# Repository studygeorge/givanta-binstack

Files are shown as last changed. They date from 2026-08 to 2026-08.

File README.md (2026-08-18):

# BINSTACK — настольный органайзер электронщика

**GIVANTA MASTERS** · мебель для тех, кто делает вещи руками

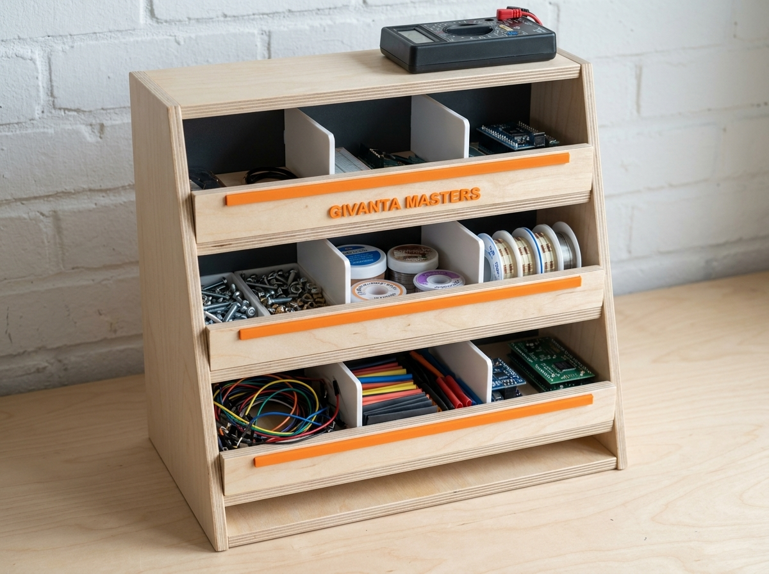
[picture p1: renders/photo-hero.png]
BINSTACK


Трёхъярусный настольный минишкафчик с наклонными открытыми лотками: винтики,
флюсы, припой, провода, термоусадка — всё видно и всё на расстоянии пальцев.
Спроектирован в Fusion 360. **Две версии в одном репозитории**: из фанеры
12 мм и полностью печатная на 3D-принтере (детали до 250×250×250 мм).

---

## Кому и зачем

Рабочее место электронщика: паяешь, собираешь макетки, прошиваешь
микроконтроллеры. Каждый ярус наклонён на 12° — содержимое сползает к
переднему бортику, откуда его удобно брать. Перегородки делят ярус на три
отсека: крепёж / химия и припой / провода. Верх — полочка под мультиметр.

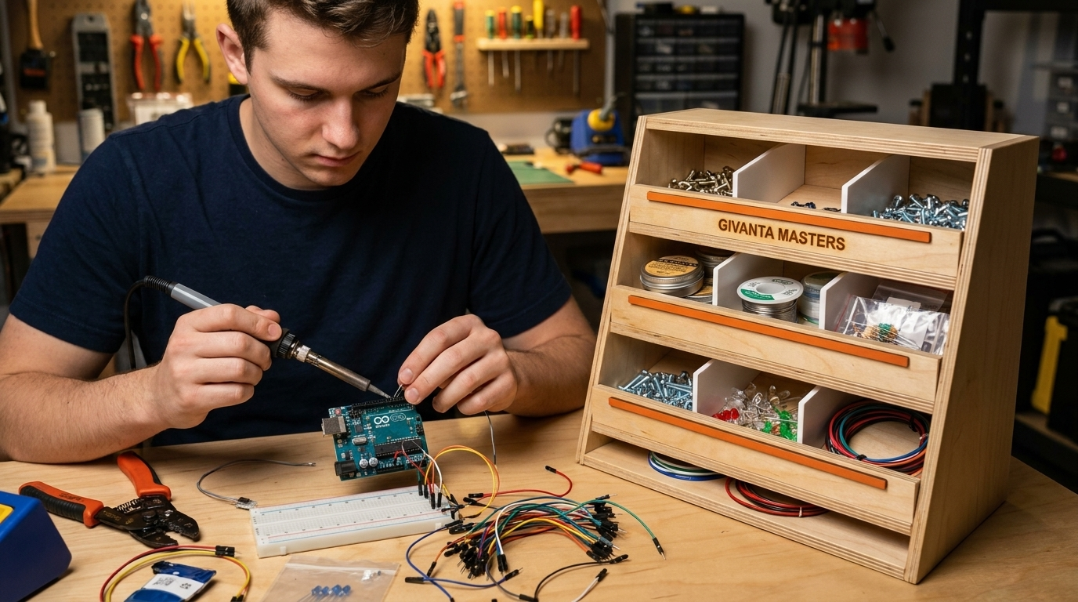
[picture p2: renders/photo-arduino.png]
За работой


## Версия из фанеры

Габарит 420 × 240 × 390 мм, берёзовая фанера 12 мм + ХДФ 6 мм.

| | |
|---|---|
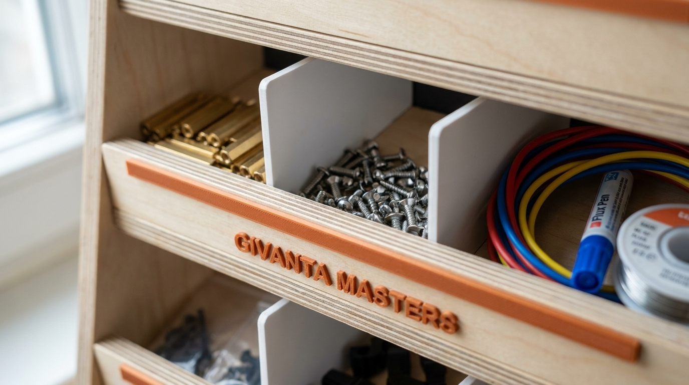
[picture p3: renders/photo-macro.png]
Фото
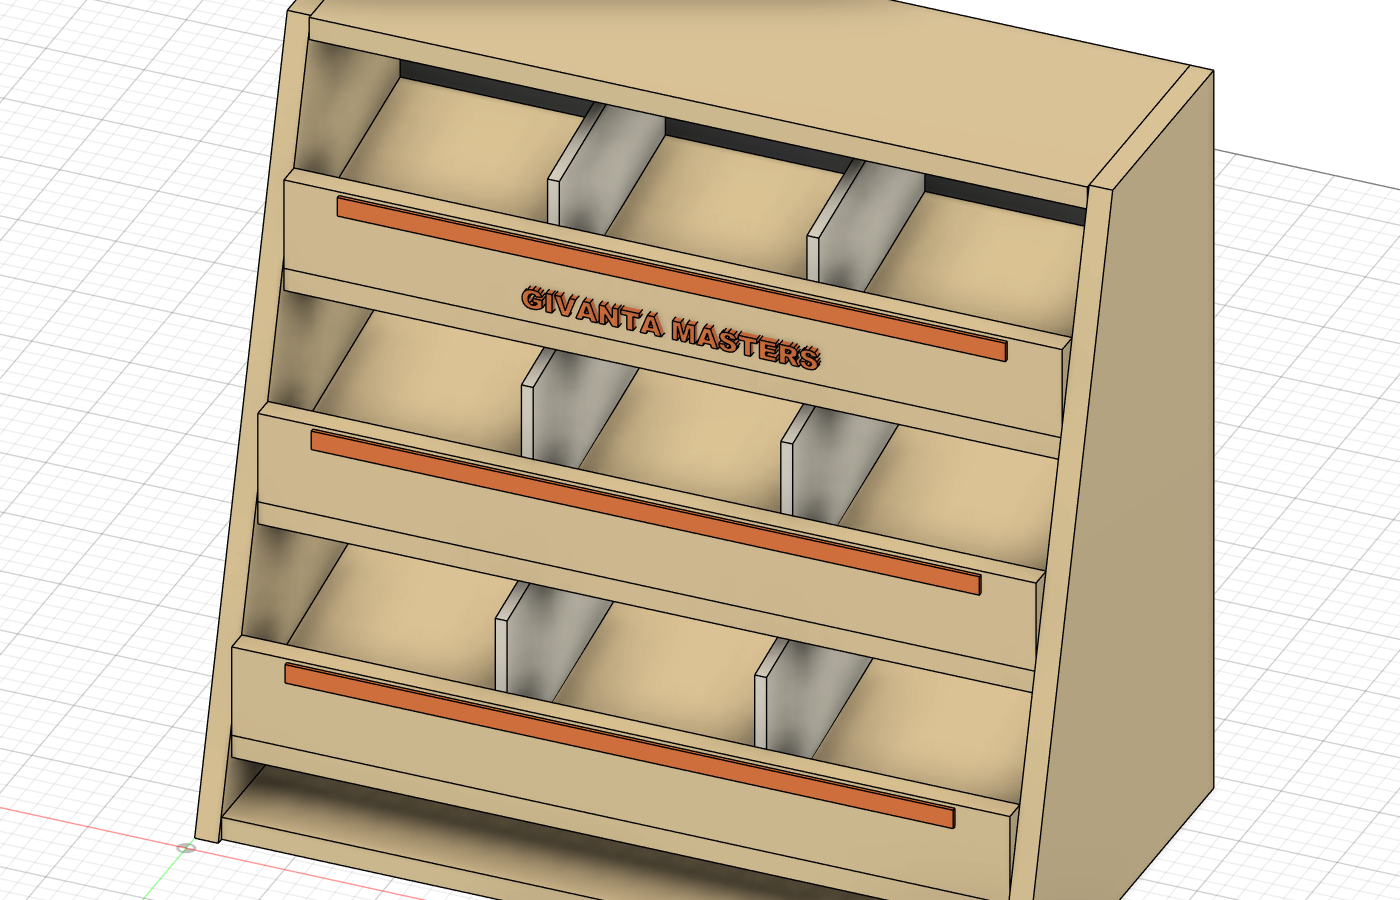
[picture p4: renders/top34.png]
Модель
|  |  |

- Косые боковины, три наклонных лотка с бортиками 48 мм
- 9 отсеков (перегородки переставные), полочка сверху
- Оранжевые маркировочные планки на бортиках — печать PETG
- Сборка на шканты 6×30 и клей ПВА, ~1 час
- Карта раскроя: [docs/cutlist.csv](docs/cutlist.csv)

**Чертёж** (SVG также в [docs/drawings](docs/drawings)):

Чертёж BINSTACK

## Печатная версия BINSTACK P

Для тех, у кого есть 3D-принтер и нет циркулярки. Все детали помещаются на
стол 250×250×250, печать **без поддержек**, комплект ~445 г PETG
(боковины облегчены фермой, см. ниже).

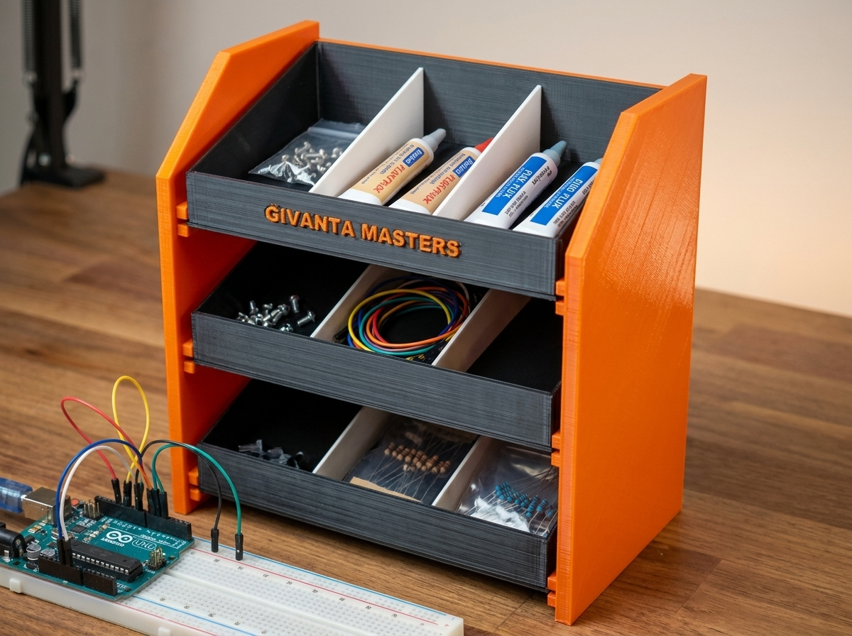
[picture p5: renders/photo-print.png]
Печатная версия


| | |
|---|---|
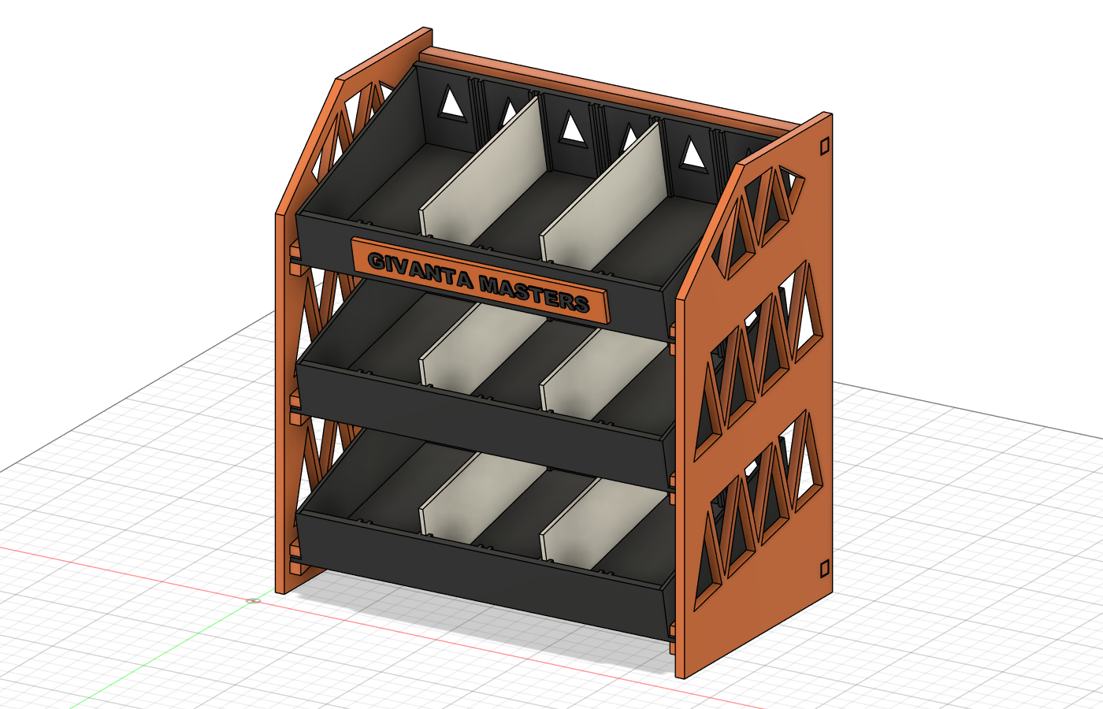
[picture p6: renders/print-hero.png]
Сборка
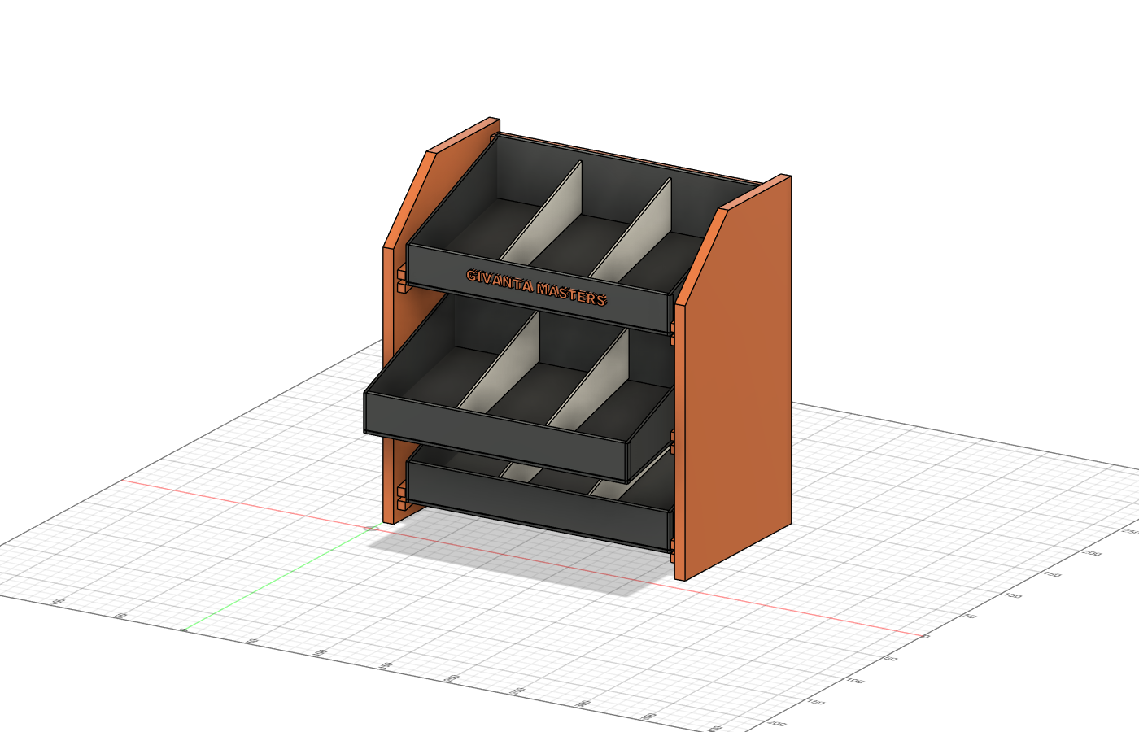
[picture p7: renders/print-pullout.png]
Выдвижение лотка
|  |  |

Конструкция: две боковины-лесенки с интегрированными полозьями под 12°,
лотки задвигаются как ящики, две штанги стягивают каркас.

**На чём лоток ездит:**
- **Дно лотка шире корпуса на 6 мм с каждой стороны.** Эти выступающие
  фланцы и есть салазки: они лежат в пазу между верхним и нижним полозом
  боковины (перекрытие 5,5 мм). Паз 3,2 мм, дно 2,4 мм — зазор 0,4 на
  сторону по нашей базе печати. Больше в конструкции ничего не требуется:
  ни направляющих, ни метизов.
- Наклон 12° работает на удержание: сам лоток внутрь не сползает, а ход
  назад ограничен задними штангами.

**На чём держатся перегородки:**
На передней и задней стенке лотка напечатаны пары рёбер, образующие
вертикальный паз 3,2 мм. Перегородка (2,4 мм) вставляется в него сверху,
стоит на дне и торцами упирается в стенки: вбок не ездит, не падает,
вынимается вверх пальцами. Пазов **5 на лоток** (шаг 33 мм), так что
перегородки переставляются под размер того, что в них лежит: от одного
широкого отсека до шести узких (перегородки докупать не нужно, просто
напечатать ещё — деталь одна и та же).
- **Детент-упор** — главное, что держит лоток от произвольного выезда. На
  переднем конце каждого нижнего полоза напечатан бугорок 1,0 мм с пологим
  въездом и крутым сходом (люфт паза 0,8 плюс натяг 0,2, поэтому дно
  поджимается и щёлкает, а не просто переезжает ступеньку). Дно лотка перещёлкивается через него с ощутимым
  усилием: закрытый лоток не выедет от тряски стола или толчка, а на выезде
  бугорок ловит лоток, не давая ему выпасть из полозьев целиком.
  Чтобы снять лоток полностью — приподнять перед и протянуть через упор.
- **Движение**: тянешь за передний бортик, щелчок — лоток выехал; толкаешь
  назад до упора в штангу, щелчок — закрыт.

Полозья и детент
- **Каркас** собирается на сквозные шипы: у каждой штанги на торцах шипы
  6×6×8, они проходят через окна 7×7 в боковинах и выходят заподлицо
  снаружи — столярный узел, никакого клея. При желании фиксируется каплей
  цианакрилата или самореза в торец шипа.

**Раскладка на столе принтера 250×250** — 5 столов на комплект:
боковина (стол целиком, полозьями вверх), боковина зеркальная, и три стола
«лоток + 2 перегородки + штанга» (штанги на первых двух из них):

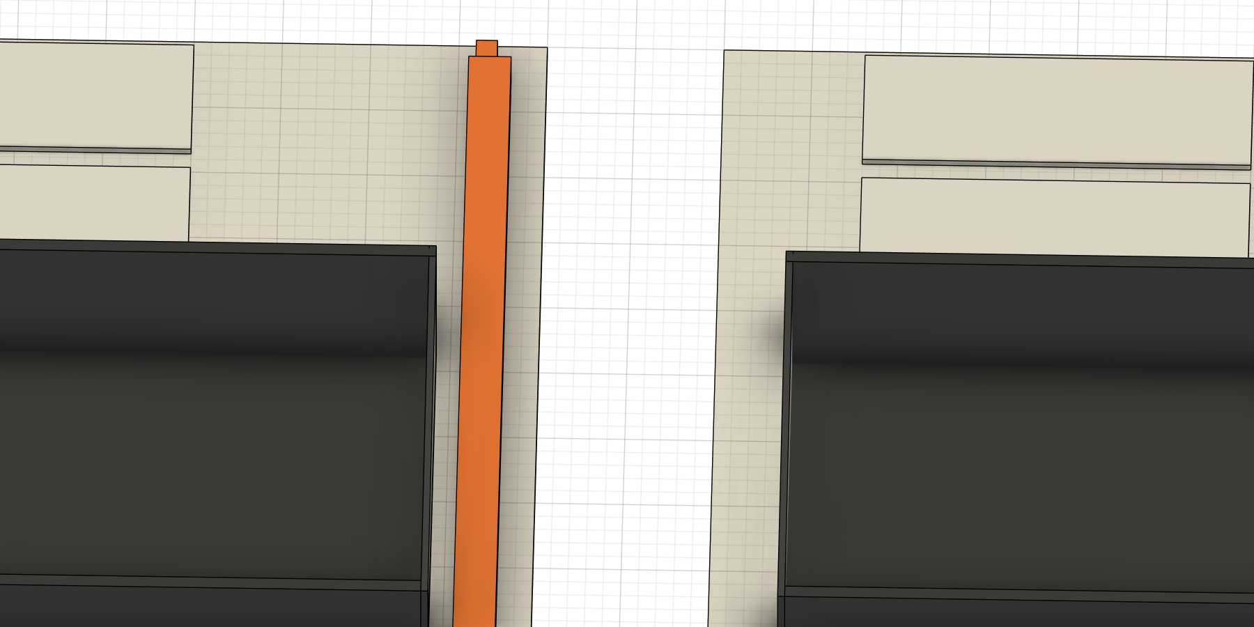
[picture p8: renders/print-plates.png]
Раскладка печати


| Файл | Деталь | Кол-во | Ориентация печати |
|---|---|---|---|
| [print/bp-side-panel.stl](print/bp-side-panel.stl) | боковина-ферма с полозьями и детентами, 240×150×11 | 2 (одна зеркально) | плашмя, полозьями вверх |
| [print/bp-bin.stl](print/bp-bin.stl) | лоток 213×117×45 (дно с фланцами-салазками) | 3 | дном вниз |
| [print/bp-stretcher.stl](print/bp-stretcher.stl) | штанга с шипами, 222 мм | 2 | лёжа |
| [print/bp-divider.stl](print/bp-divider.stl) | перегородка 109×40×2,4 | 6 (или больше) | плашмя |
| [print/bp-logo-strip.stl](print/bp-logo-strip.stl) | планка с логотипом, 138×17×3 | 1 | лицом вверх |

**Планка логотипа — двухцветная.** Буквы выступают ровно на 0,8 мм над
планкой и лежат выше всей её толщины, поэтому цвет меняется одной паузой:
печатать лицом вверх и поставить смену филамента на высоте **3,0 мм**
(в Creality Print: правый клик по слою → Add color change). Оранжевая
планка, графитовые буквы. Если менять филамент не хочется, деталь
печатается одним цветом и буквы читаются рельефом.

Режим: PETG, сопло 0,4, слой 0,2, заполнение 15 %, стенки 3 периметра.
Посадки: паз полоза 3,2 мм под дно 2,4 (зазор 0,4 на сторону), шипы штанг
6×6 в карманы 7×7. Зеркальную боковину слайсер делает функцией Mirror.

### Облегчение по сопромату

Боковины сделаны не сплошными пластинами, а **фермами** — как рама
велосипеда, где металл стоит только там, где работает.

Ферма боковины

Расчёт: при 4,5 кг груза (три полных лотка) на боковину приходится 22 Н.
Сдвиг в стенке 0,018 МПа против предела PETG ~50 МПа, изгиб полоза 0,06 МПа.
**Запас по прочности ~2700 крат** — то есть прочность вообще не ограничивает
конструкцию, ограничивает только жёсткость. Поэтому материал убран из всех
зон, где он не работает:

| Что оставлено | Зачем |
|---|---|
| силовой контур 7 мм по периметру | момент инерции сечения: чем дальше материал от нейтральной оси, тем выше жёсткость |
| полосы 4 мм вдоль полозьев | локальная нагрузка от фланцев лотков |
| раскосы 4 мм треугольной решёткой | треугольник не деформируется без изменения длины сторон, поэтому ферма держит форму при минимуме материала |
| перемычки у окон под шипы | концентрация напряжений в узле каркаса |
| толщина стенки 5 мм вместо 8 | стенка сдвинута к полозьям, посадки лотков не изменились |

Проёмы наклонены вдоль полозьев на 12°, углы у них тупые (нет острых
концентраторов, от которых по слоям идёт трещина). Отверстия сквозные по
толщине, поэтому при печати плашмя **нависаний не возникает вообще**.

Ферма покрывает и клин над верхним полозом, а у лотков треугольными
проёмами облегчены задние стенки: низ борта 17 мм оставлен сплошным, чтобы
мелочь не просыпалась, а сами проёмы стоят **строго между пазами
перегородок** и их рёбер не касаются.

Каждый проём проходит три проверки, иначе не режется вовсе: площадь ≥ 200 мм²,
радиус вписанной окружности ≥ 4,5 мм и отношение этого радиуса к длинной
стороне ≥ 0,13. Последнее отсекает вырожденные щели и обрезки у краёв —
поэтому в узком клине под нижним полозом материал намеренно оставлен
сплошным: там аккуратный проём не помещается.

Результат: боковина **272 → 131 см³ (−52 %)**, лоток 132 → 128 см³,
комплект целиком 771 см³. По факту слайсинга это **503 г PETG и 31 ч 39 мин** печати (см. замеры ниже).

### Профиль печати: минимум пластика и времени

Числа под Creality K2, сопло 0,4, PETG 230–240 °C / стол 70–80 °C.

**Когда слайсер перестаёт лить сплошняк.** Ширина линии для сопла 0,4 равна
0,42 мм, поэтому при 2 периметрах деталь толщиной до **1,7 мм печатается
насквозь сплошной**, от 1,7 до 2,1 мм слайсер добивает остаток gap fill —
это тоже сплошной пластик, и только **от 2,1 мм** внутри появляется полость
с заполнением. При 3 периметрах те же пороги сдвигаются до 2,5 и 2,9 мм.

| Толщина элемента | 2 периметра | 3 периметра |
|---|---|---|
| до 1,7 мм | сплошняк | сплошняк |
| 1,7–2,1 мм | сплошняк (gap fill) | сплошняк |
| 2,1–2,5 мм | **полость с заполнением** | сплошняк |
| 2,5–2,9 мм | полость | сплошняк (gap fill) |
| от 2,9 мм | полость | **полость** |

**Что получится в стенке 5 мм.** Боковина печатается плашмя, поэтому 5 мм
это высота по Z (20 слоёв по 0,25), а ширина раскоса 4 мм лежит на столе.
В сечении раскоса 4 × 5 мм:

| | Размер | Доля сечения |
|---|---|---|
| сплошные верхние слои | 0,75 мм (3 слоя) | |
| сплошные нижние слои | 0,75 мм (3 слоя) | |
| сплошные периметры по бокам | 0,84 + 0,84 мм | |
| **всего сплошного** | **11,9 мм²** | **59 %** |
| **полость** | 2,32 × 3,50 мм = **8,1 мм²** | **41 %** |
| в полость идёт Gyroid 10 % | 0,8 мм² | |
| **итого пластика** | **12,7 мм²** из 20 | **63 %** |

Сечение раскоса

**По слоям (Z).** Стенка 5 мм при слое 0,25 это ровно 20 слоёв:

| Слои | Z, мм | Что печатает принтер |
|---|---|---|
| 1–3 | 0 … 0,75 | сплошная нижняя корка, 100 % |
| 4–17 | 0,75 … 4,25 | **Gyroid 10 %**, 14 слоёв = 3,50 мм |
| 18–20 | 4,25 … 5,0 | сплошная верхняя корка, 100 % |

Гироид идёт только в полости шириной 2,32 мм: по краям раскоса на всех
20 слоях всё равно печатаются два периметра 0,84 мм — они сплошные всегда.
При 2 корках вместо 3 раскладка становится 0,50 / 4,00 / 0,50 мм.

Если нужно ещё легче — поставить 2/2 слоя вместо 3/3, будет 58 %.
Три периметра ставить нельзя: полость схлопнется до 1,5 мм, а пластика
станет 77 %, то есть почти сплошняк.

Поэтому раскосы фермы сделаны **4 мм**: при 2 периметрах внутри остаётся
2,3 мм полости, то есть раскос печатается как две стенки с воздухом внутри,
а не бруском пластика. Перегородка (2,4 мм) наоборот идёт сплошняком из
периметров — заполнение ей просто не нужно.

| Деталь | Слой | Стенки | Заполнение | Дно/верх |
|---|---|---|---|---|
| боковина-ферма | 0,25 | 2 | **Lightning 5 %** | 2 / 2 |
| лоток | 0,25 | 2 | Lightning 5 % | 4 / 3 |
| перегородка 2,4 мм | 0,25 | 2 | не нужно: деталь целиком из периметров | 2 / 2 |
| штанга | 0,25 | 3 | Gyroid 15 % (несёт каркас) | 3 / 3 |
| планка логотипа | 0,2 | 2 | 10 % | 3 / 4 |

**Какой узор выгоднее — замерено, а не прикинуто.** Боковина-ферма
нарезана в Creality Print CLI под PETG, слой 0,25, 2 периметра, 3/3 корки,
заполнение 10 %:

| Узор | Время | Пластик |
|---|---|---|
| **Lightning** | **7 ч 10 мин** | **65,1 г** |
| Grid | 7 ч 54 мин | 75,2 г |
| Rectilinear | 7 ч 54 мин | 75,2 г |
| Gyroid | 7 ч 59 мин | 76,0 г |
| Honeycomb | 8 ч 48 мин | 79,0 г |

Lightning выигрывает и по времени, и по расходу: минус 11 г и 49 минут
против Gyroid на каждой боковине. Grid и Rectilinear в этой детали дают
идентичный результат, соты — худший вариант по обоим параметрам.

Дожимаем корками и процентом (тот же Lightning):

| Настройка | Время | Пластик |
|---|---|---|
| 10 %, корки 3/3 | 7 ч 10 мин | 65,1 г |
| 10 %, корки 2/2 | 6 ч 58 мин | 63,5 г |
| 5 %, корки 3/3 | 6 ч 30 мин | 62,5 г |
| **5 %, корки 2/2** | **6 ч 17 мин** | **60,8 г** |

Итог: **Lightning 5 %, корки 2/2** — 60,8 г и 6 ч 17 мин против 76 г и
8 часов у Gyroid 10 % с корками 3/3. Экономия 15 г и 1 ч 40 мин на боковину,
то есть **30 г и больше трёх часов на пару**.

Почему Lightning здесь безопасен, хотя обычно он «несущим» не считается:
в раскосе шириной 4 мм полость всего 2,3 мм, и жёсткость там дают два
периметра, а не заполнение. Для штанг каркаса, где сечение 12 × 10 мм,
заполнение работает по-настоящему — там ставим Gyroid 15 %.

**Весь комплект, замерено по каждой детали** (профили из таблицы выше):

| Деталь | Шт | Время / шт | Грамм / шт | Время всего | Грамм всего |
|---|---|---|---|---|---|
| Боковина-ферма | 2 | 6 ч 17 мин | 60,8 | 12 ч 34 мин | 121,7 |
| **Лоток** | 3 | 4 ч 20 мин | **98,0** | 12 ч 59 мин | **294,1** |
| Перегородка | 6 | 36 мин | 8,7 | 3 ч 38 мин | 52,0 |
| Штанга | 2 | 58 мин | 14,7 | 1 ч 56 мин | 29,3 |
| Планка логотипа | 1 | 30 мин | 6,1 | 30 мин | 6,1 |
| **Итого** | **14** | | | **31 ч 39 мин** | **503 г** |

Важный вывод: после облегчения боковин главным потребителем стали **лотки —
58 % пластика и 41 % времени всего комплекта**. Причина в дне: 213 × 117 мм
при толщине 2,4 мм это 10 слоёв, из которых при корках 4/3 семь идут
сплошной заливкой, то есть дно печатается почти монолитом независимо от
процента заполнения. Настройками это не лечится, только геометрией
(утоньшить середину дна и добавить рёбра жёсткости) — скажи, если делать.

Общее: **без поддержек** (`enable_support: 0`), кайма 5 мм outer only,
elephant foot 0,15, скорости стенок 150–200 мм/с (PETG выше мутит
поверхность), обдув 30–50 %.

Проверять в слайсере просто: в Preview включить показ слоёв и посмотреть
срез через раскос — должны быть видны два контура и воздух между ними.
Если сплошная заливка, значит ширина линии в профиле больше 0,42 или
периметров стоит 3.

Посадки печатать слоем 0,25 и не выше: по нашей базе 0,28 экономит около
7 % времени, но портит пазы.

### Тест-кит перед печатью комплекта

Прежде чем печатать боковины целиком, проверь посадку и поведение на наклоне
маленьким китом: 33 минуты и 7,5 г PETG на все четыре купона.

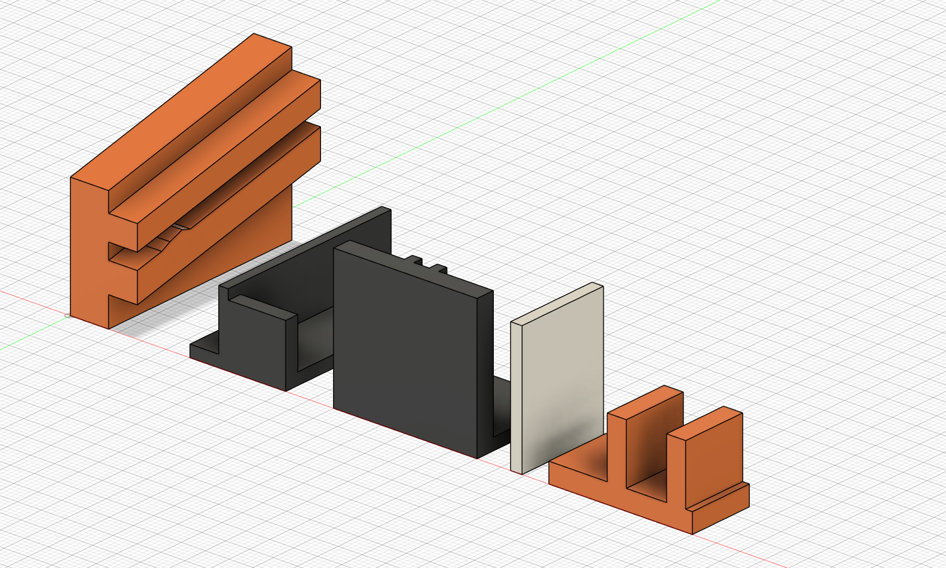
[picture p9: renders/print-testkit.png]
Тест-кит


Четыре маленьких купона с **точно теми же припусками**, что в изделии.

| Файл | Что это | Размер |
|---|---|---|
| [print/tk3-rail-coupon.stl](print/tk3-rail-coupon.stl) | кусок боковины: наклонный полоз 12° + детент | 35×26×10, 5 см³ |
| [print/tk3-slider-flange.stl](print/tk3-slider-flange.stl) | кусок дна лотка с фланцем-салазкой | 14×30×10, 2 см³ |
| [print/tk3-divider-slot.stl](print/tk3-divider-slot.stl) | кусок стенки лотка с пазом под перегородку | 24×18×12, 2 см³ |
| [print/tk3-divider.stl](print/tk3-divider.stl) | огрызок перегородки | 18×16×2,4, 1 см³ |

Все четыре купона уже лежат в печатной ориентации: высота набора 12 мм,
48 слоёв, **33 минуты и 7,5 г PETG** на всё (слой 0,25, стенки 2,
заполнение 10 %, без поддержек).

Что проверяем:

1. **Паз перегородки.** Вставь огрызок перегородки в паз купона: должен
   входить пальцем без молотка, но не болтаться. Расчётный люфт 0,8 мм
   (паз 3,2 − перегородка 2,4).
2. **Ход по полозьям.** Поставь купон полоза на торец (полозья тогда идут
   под рабочим наклоном 12°), вставь слайдер фланцем в паз и двигай: ход
   должен быть свободным, без закусывания на стыках слоёв. Перекрытие
   фланца с полозом 5,5 мм.
3. **Детент.** На выезде слайдер должен **щёлкнуть** через бугорок: он
   выше люфта на 0,2 мм, то есть дно поджимается. Задвинутый слайдер не
   должен сам стронуться, если стукнуть по столу.

Если посадка окажется тугой или болтающейся — скажи, какая именно, и все
пазы пересчитываются одним параметром в скрипте.

## CAD

Печатная версия собрана как настоящая сборка: каждая деталь это отдельный
парт с одним телом, сборка состоит из экземпляров этих партов.

| Файл | Что внутри |
|---|---|
| [cad/binstack-print-assembly.f3d](cad/binstack-print-assembly.f3d) | сборка BINSTACK P для Fusion 360: 6 партов, 14 экземпляров |
| [cad/binstack-print-assembly.step](cad/binstack-print-assembly.step) | та же сборка в нейтральном формате |
| [cad/parts/](cad/parts) | каждый парт отдельным файлом: боковины, лоток, перегородка, штанга, планка |
| [cad/binstack-full.step](cad/binstack-full.step) | фанерная версия |

Состав сборки: боковина левая ×1, боковина правая ×1, лоток ×3,
перегородка ×6, штанга ×2, планка логотипа ×1.

## Серия GIVANTA MASTERS

- [WORKSHOP ONE](https://github.com/studygeorge/givanta-workshop-one) — верстак инженера + башня 3D-принтера

## Лицензия

CC BY 4.0 — стройте, печатайте, дорабатывайте. Указывайте авторство:
**GIVANTA MASTERS**.

---

*GIVANTA MASTERS · 2026*

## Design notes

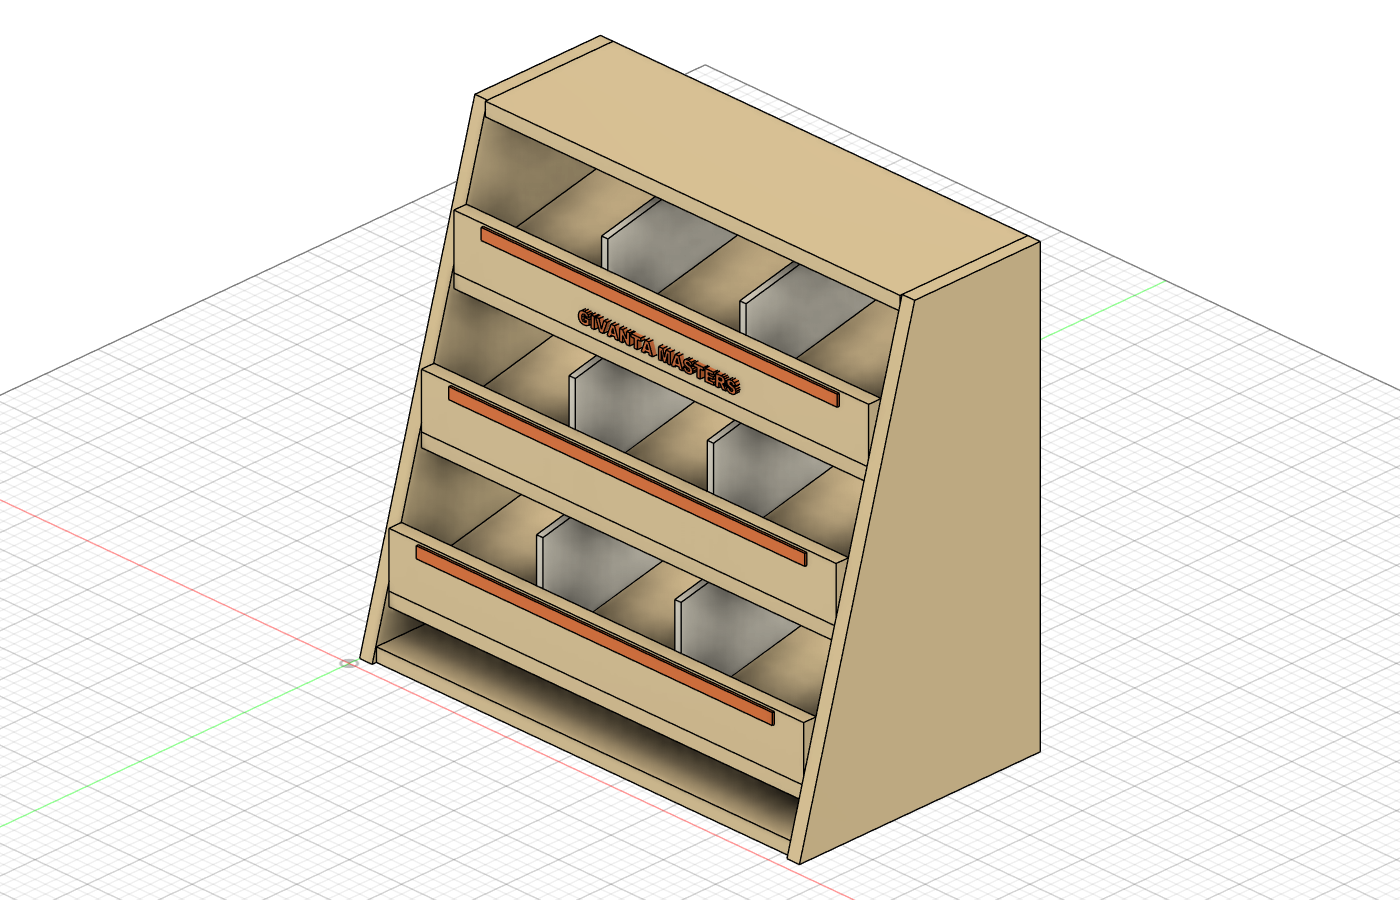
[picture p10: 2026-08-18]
renders/hero.png

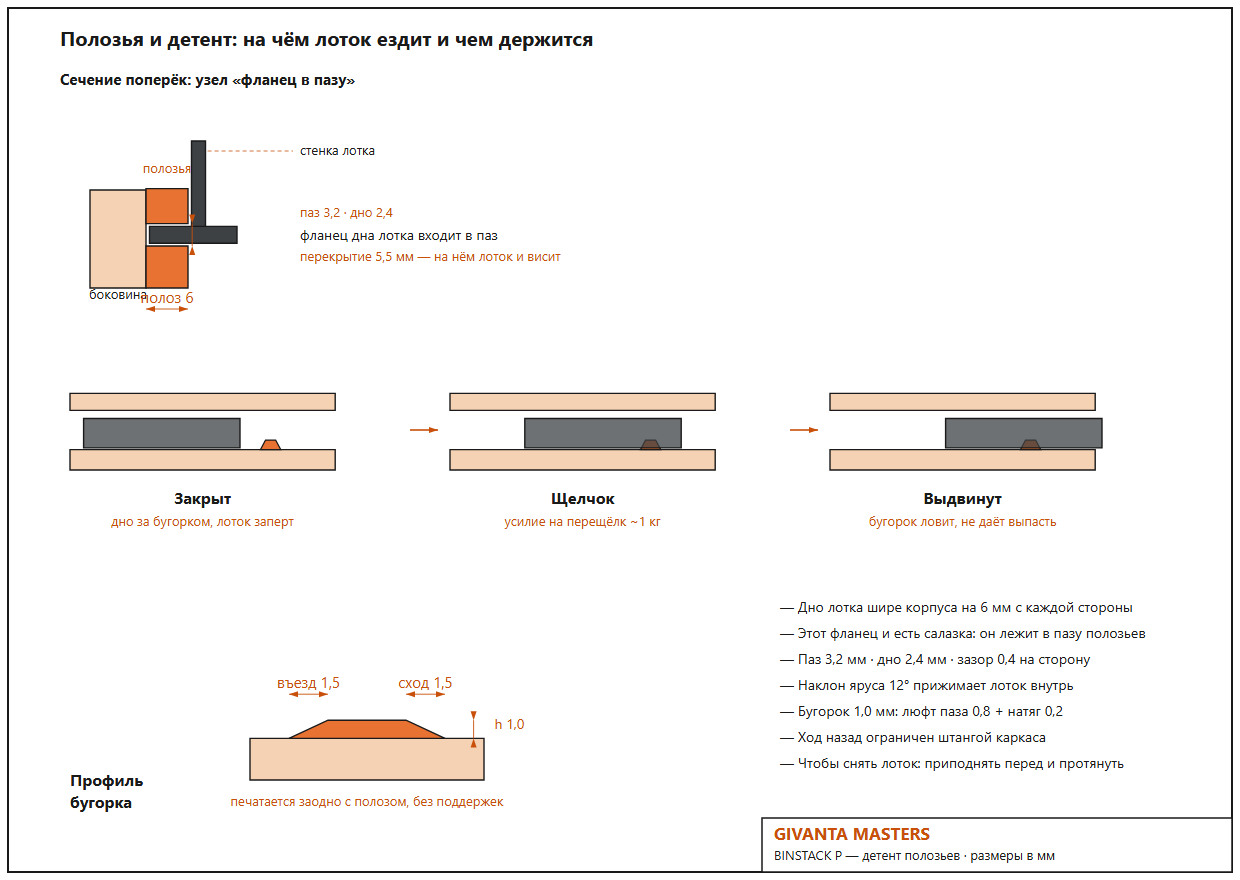
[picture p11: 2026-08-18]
docs/drawings/detent.png

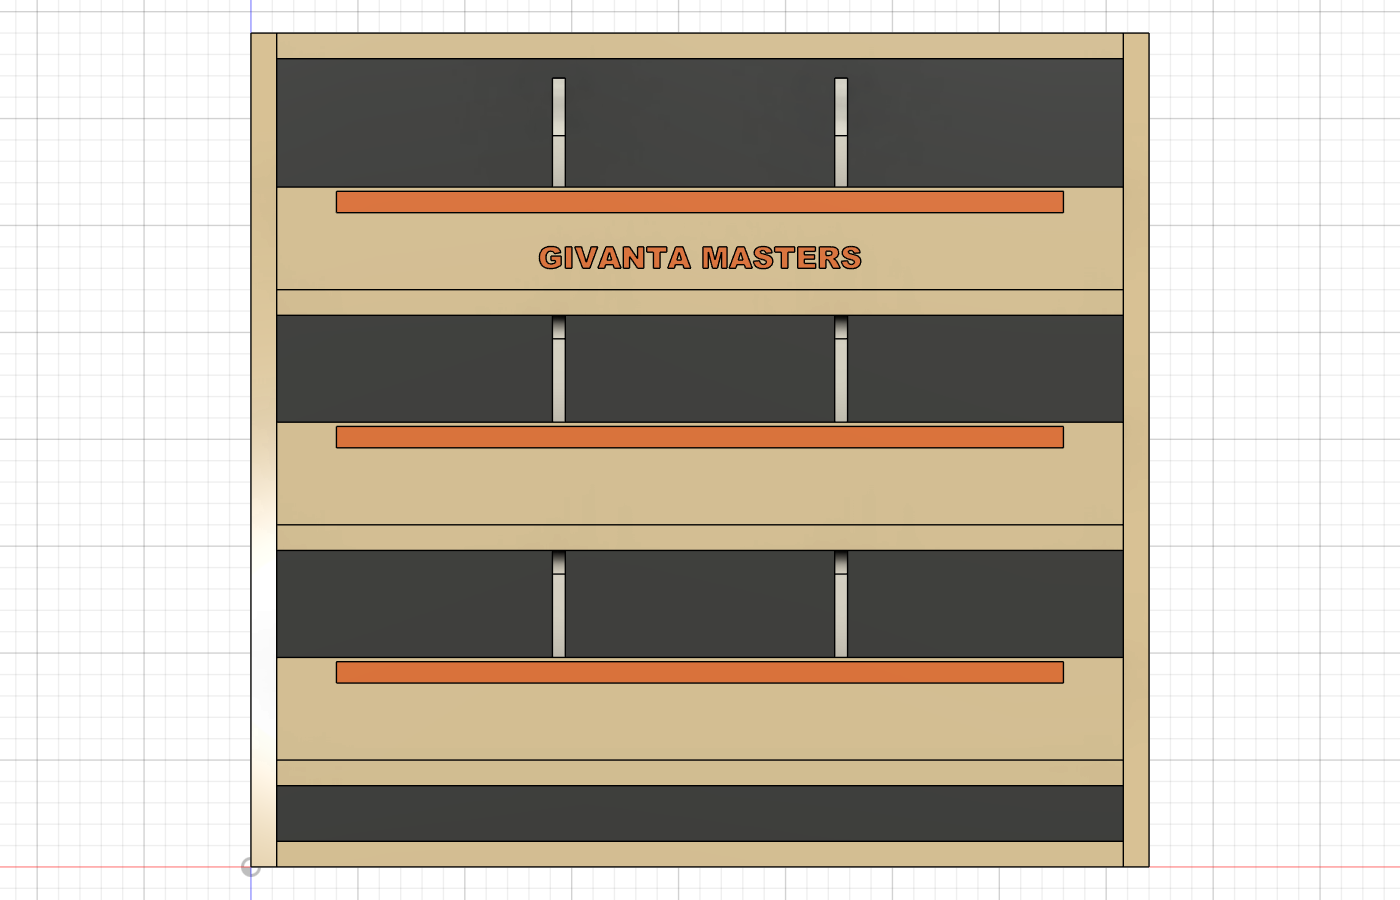
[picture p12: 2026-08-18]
renders/front.png

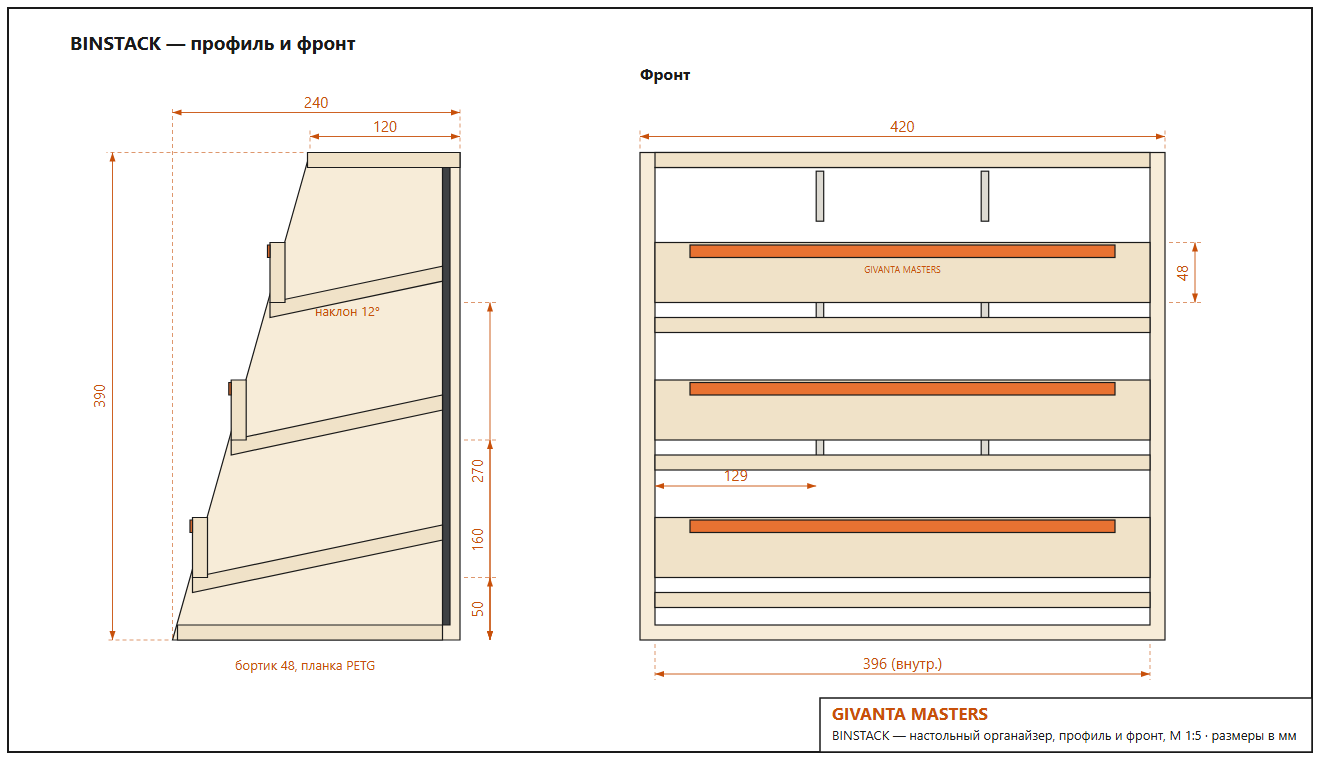
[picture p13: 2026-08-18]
docs/drawings/binstack.png

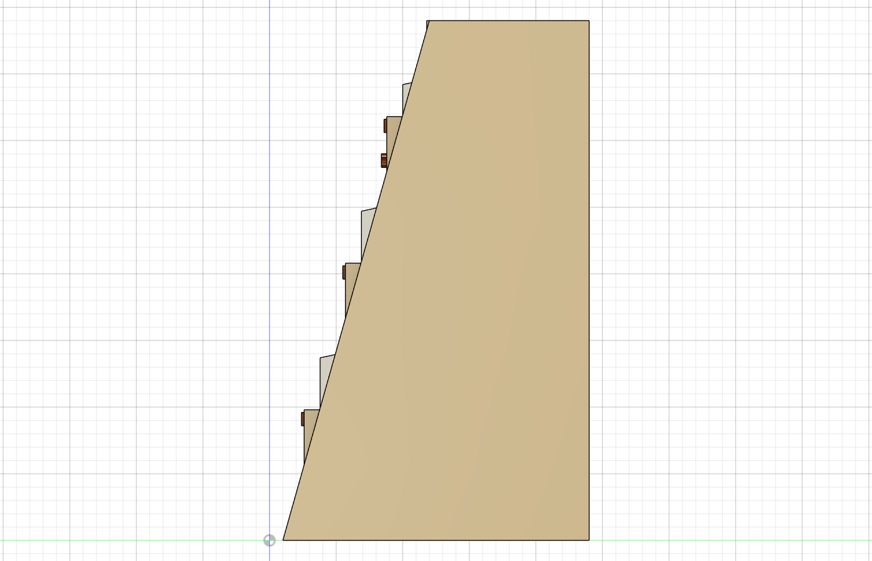
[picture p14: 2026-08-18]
renders/side.png

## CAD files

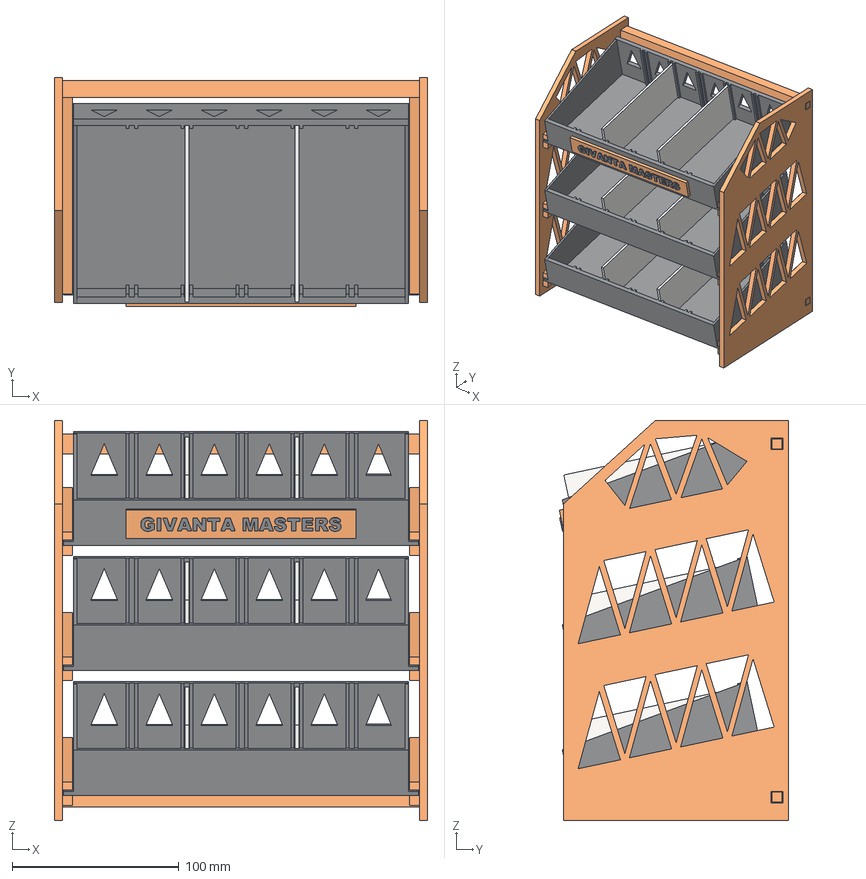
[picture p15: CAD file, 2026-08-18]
cad/binstack-print-assembly.step
224.0 x 137.6 x 240.0 mm

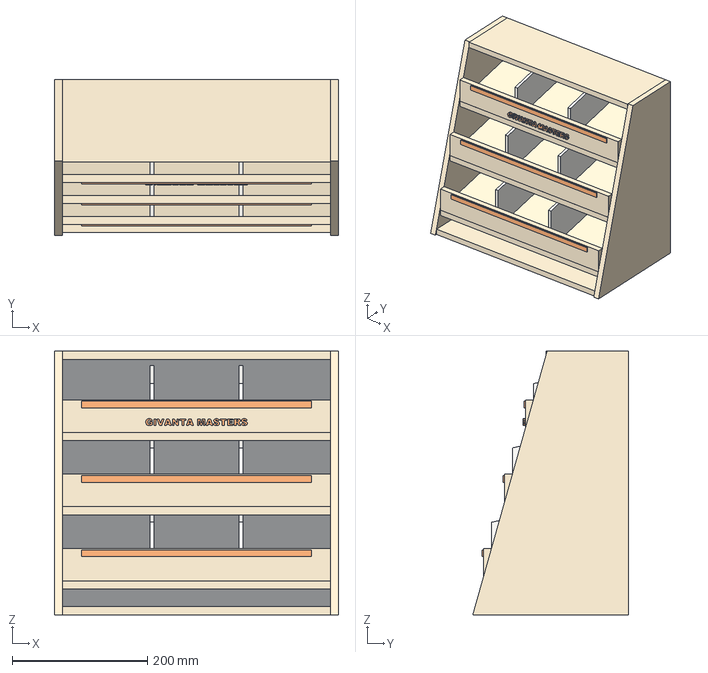
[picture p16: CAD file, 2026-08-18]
cad/binstack-full.step
420.0 x 230.0 x 390.0 mm

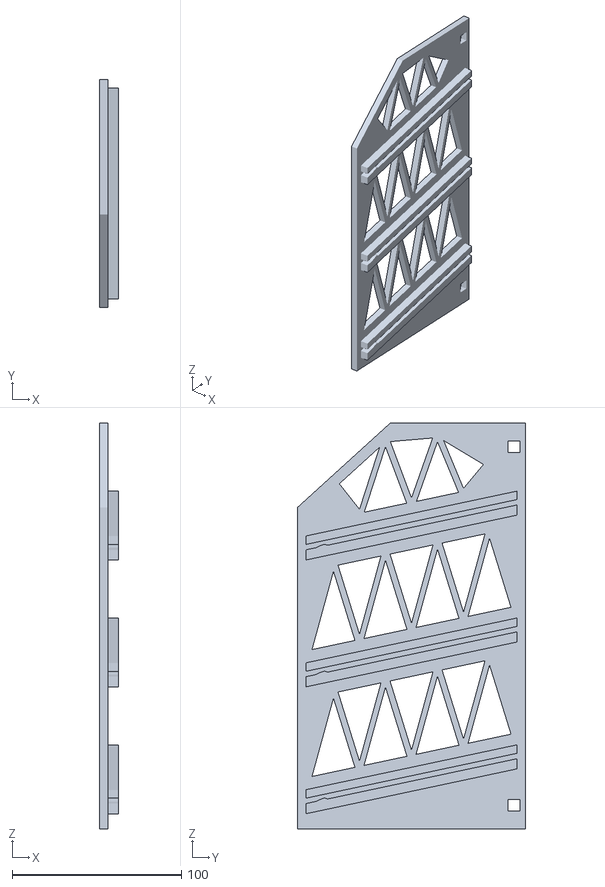
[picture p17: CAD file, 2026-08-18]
print/bp-side-panel.stl
11.0 x 135.0 x 240.0

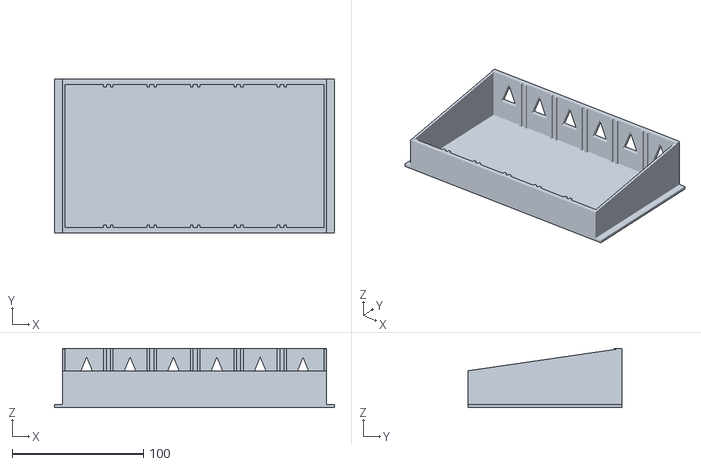
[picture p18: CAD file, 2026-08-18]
print/bp-bin.stl
213.0 x 117.0 x 45.0

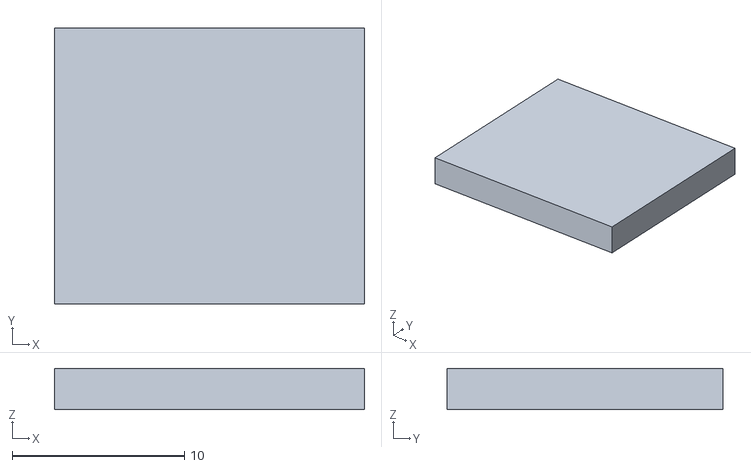
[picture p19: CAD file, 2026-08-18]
print/tk3-divider.stl
18.0 x 16.0 x 2.40

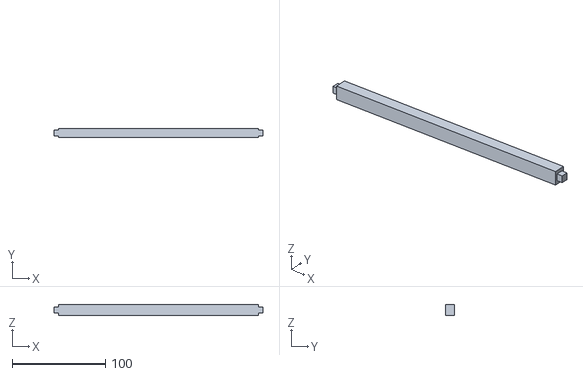
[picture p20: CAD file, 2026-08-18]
print/bp-stretcher.stl
224.0 x 10.0 x 12.0

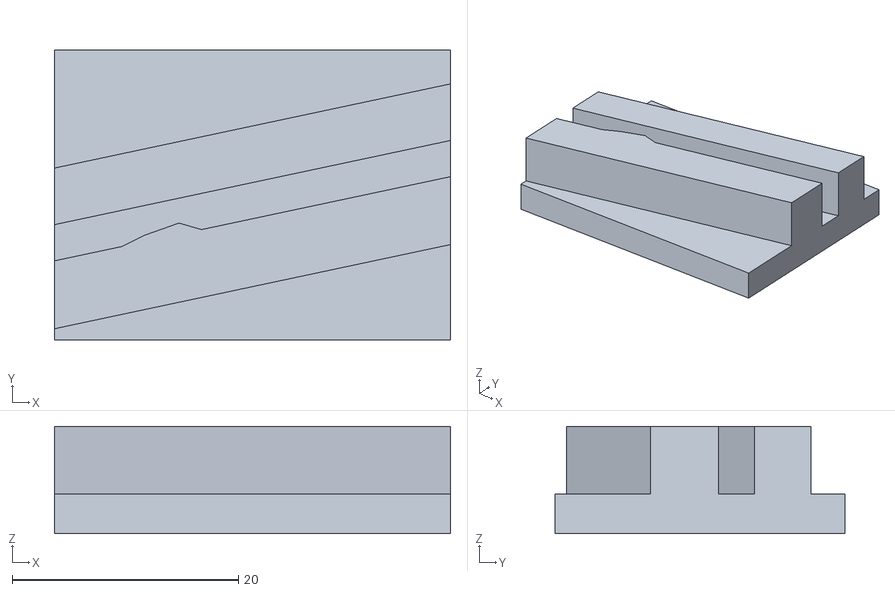
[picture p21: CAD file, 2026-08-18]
print/tk3-rail-coupon.stl
35.0 x 25.6 x 9.50

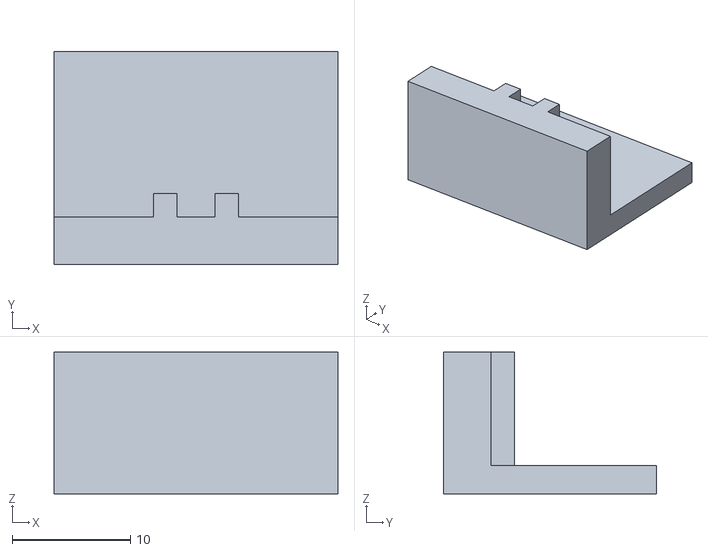
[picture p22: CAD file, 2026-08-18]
print/tk3-divider-slot.stl
24.0 x 18.0 x 12.0

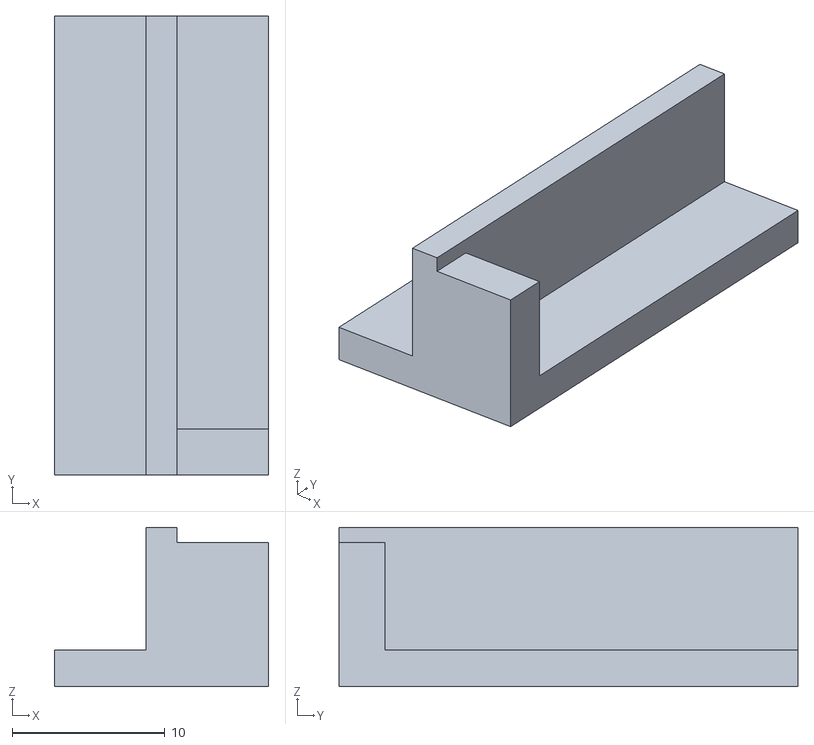
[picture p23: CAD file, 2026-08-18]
print/tk3-slider-flange.stl
14.0 x 30.0 x 10.4

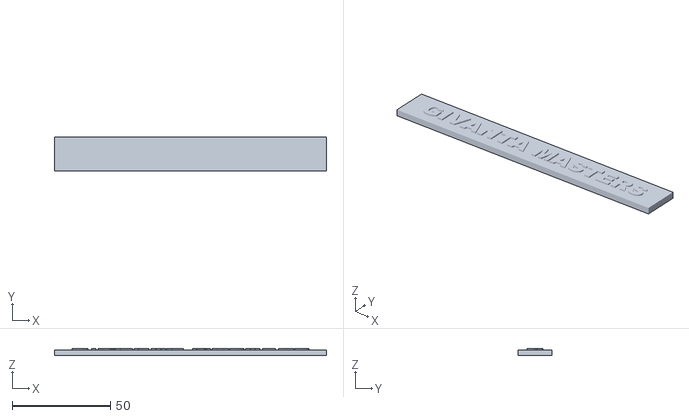
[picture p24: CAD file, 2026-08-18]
print/bp-logo-strip.stl
138.3 x 17.3 x 3.80

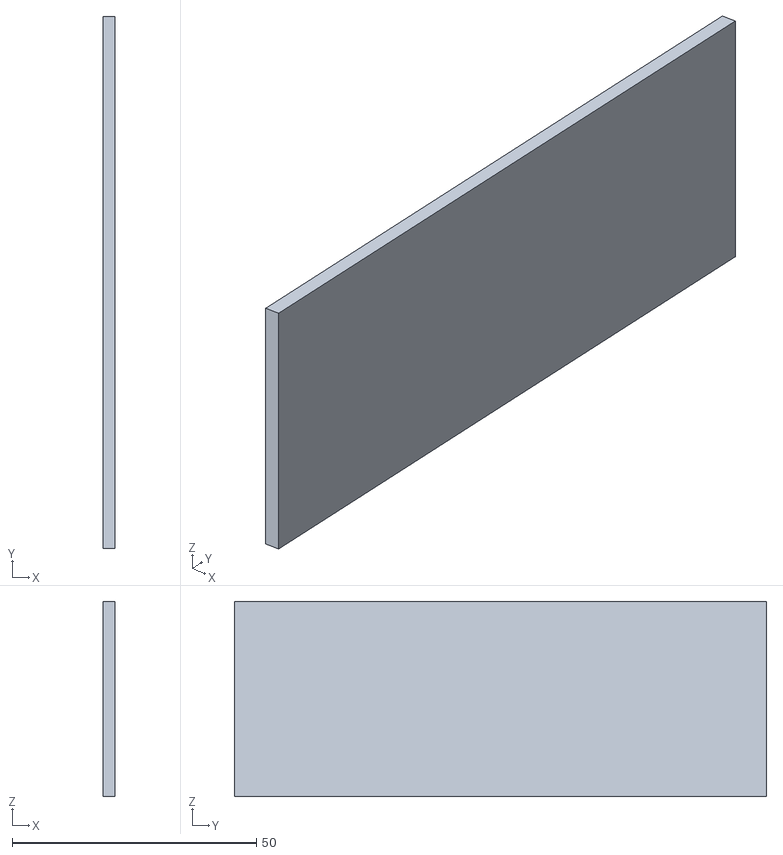
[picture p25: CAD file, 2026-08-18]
print/bp-divider.stl
2.40 x 109.0 x 40.0

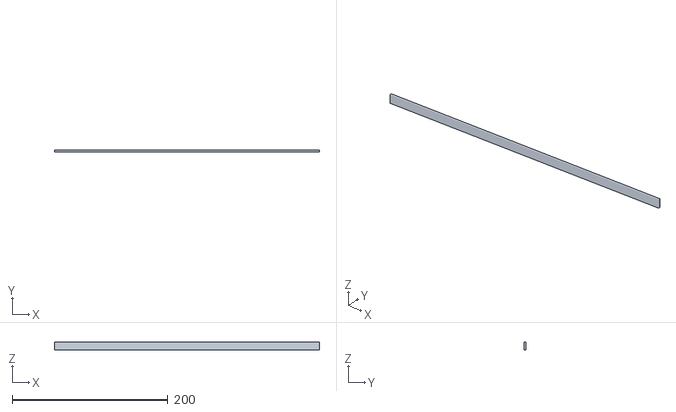
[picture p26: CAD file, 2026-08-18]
print/label-strip-340mm.stl
340.0 x 2.00 x 10.0

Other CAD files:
cad/binstack-print-assembly.f3d
cad/binstack-test-kit.f3d
cad/parts/bin.f3d
cad/parts/divider.f3d
cad/parts/logo-strip.f3d
cad/parts/side-panel-left.f3d
cad/parts/side-panel-right.f3d
cad/parts/stretcher.f3d

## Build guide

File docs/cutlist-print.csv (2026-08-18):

Модуль | Деталь | Длина, мм | Ширина, мм | Толщина/высота, мм | Материал | Кол-во
BINSTACK P | Боковина с полозьями | 240 | 150 | 8 | PETG | 2
BINSTACK P | Штанга с шипами | 224 | 12 | 10 | PETG | 2
BINSTACK P | Лоток | 201 | 120 | 47 | PETG | 3
BINSTACK P | Перегородка лотка | 110 | 40 | 2 | PETG | 6

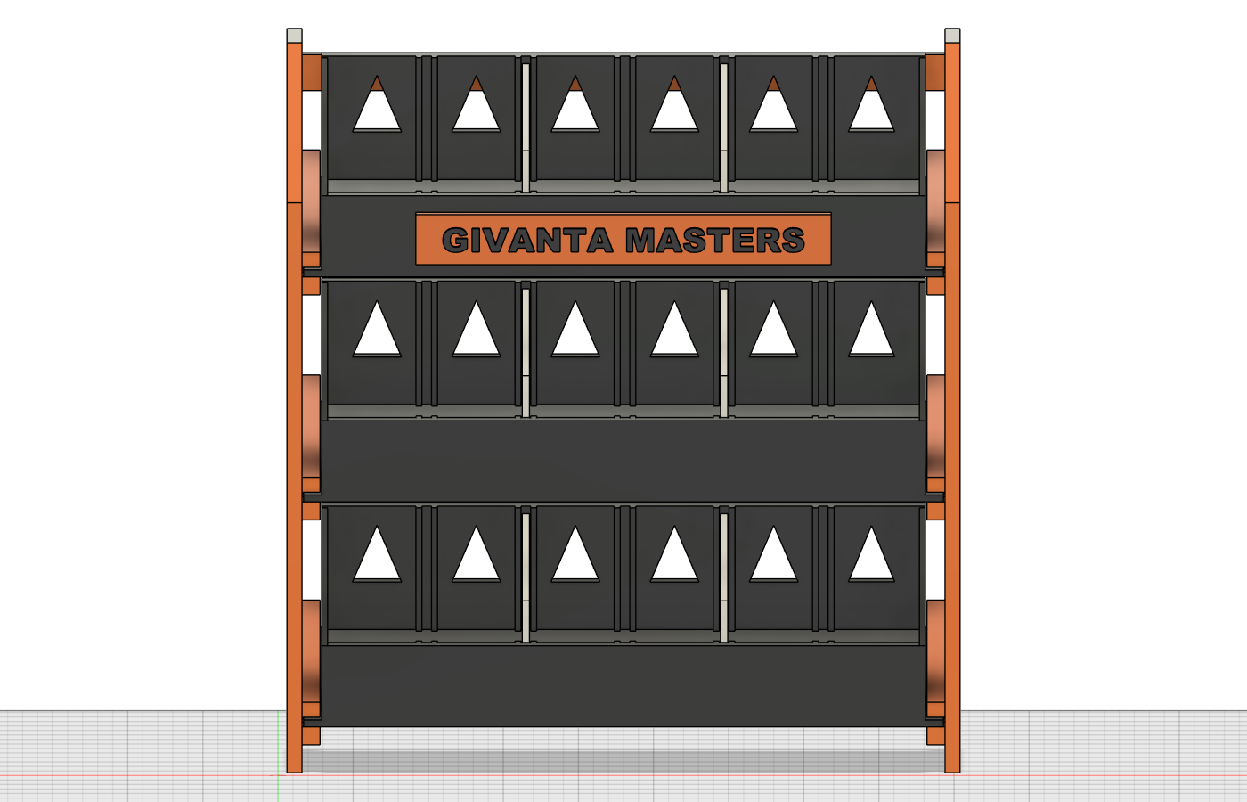
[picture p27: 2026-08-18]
renders/print-front.png

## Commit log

2026-08-18 BINSTACK: настольный органайзер электронщика, фанера + печатная версия
    Трёхъярусный каскад с наклонными лотками 12°: фанера 12 мм (420x240x390)
    и BINSTACK P целиком из PETG (детали до 250x250, без поддержек).
    Рендеры, чертёж, карты раскроя, STEP, STL.
    [binstack-full.step, binstack-print-full.step, bp-bin.stl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]
2026-08-18 BINSTACK P: сквозные шипы штанг, раскладка печати по столам 250x250
    Окна 7x7 в боковинах, шипы штанг 6x6x8 заподлицо, кадры выдвижения
    лотка и раскладки на 5 столов, обновлённые STEP и STL штанги.
    [binstack-print-full.step]
2026-08-18 Тест-кит полозьев: купон с зазорами 2.9/3.2/3.5, клин 12°, слайдер
    Малая проверка перед печатью комплекта: посадка дна в паз и удержание
    на рабочем наклоне. Стол 6 в модели, три STL, протокол в README.
    [tk-rail-coupon.stl, tk-slider.stl, tk-wedge-12deg.stl]
2026-08-18 Детенты-упоры на полозьях, компактный тест-кит, схема работы упора
    Бугорок 0.7 мм на переднем конце каждого нижнего полоза: лоток
    перещёлкивается с усилием и не выезжает произвольно, на выходе упор ловит
    его от выпадения. Купон уменьшен до 70x80 и получил детенты, схема detent.svg.
    [binstack-print-full.step, bp-bin.stl, bp-divider.stl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]
2026-08-18 BINSTACK P пересобран как настоящая сборка из партов
    Каждая деталь теперь отдельный компонент с одним телом в локальных
    координатах, сборка состоит из экземпляров: боковины x2, лоток x3,
    перегородка x6, штанга x2, планка логотипа x1. Логотип вынесен из лотка
    в отдельную печатную планку. Добавлены f3d сборки и партов, документ
    Fusion сохранён под именем GIVANTA BINSTACK P Assembly.
    [bin.f3d, binstack-print-assembly.f3d, binstack-print-assembly.step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]
2026-08-18 Лоток встаёт в паз: дно с фланцами-салазками, крупнее логотип
    Дно лотка расширено на 6 мм с каждой стороны — фланцы входят в паз
    полозьев с перекрытием 5.5 мм, на них лоток и висит (до этого дно
    заканчивалось до паза и держаться было не на чем). Планка логотипа
    увеличена до 125x17, кегль 9 мм — надпись стала ровной. Схема дополнена
    поперечным сечением узла.
    [bin.f3d, binstack-print-assembly.f3z.f3d, binstack-print-assembly.step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]
2026-08-18 Перегородки встают в пазы, логотип двухцветный
    Перегородки держались ничем и резали заднюю стенку: теперь на передней и
    задней стенках лотка по 5 пар рёбер, образующих паз 3.2 мм под перегородку
    2.4 мм — вставляется сверху, упирается торцами, переставляется по шагу 33.
    Буквы логотипа вынесены отдельным телом графитового цвета и выступают на
    0.8 мм над планкой: печатается сменой филаме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
    [bin.f3d, binstack-print-assembly.f3d, binstack-print-assembly.f3z.f3d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]
2026-08-18 Логотип: планка строится по фактическим габаритам текста
    Буквы вылезали за верхнюю и правую кромку планки — размер планки был задан
    заранее, а текст под него не проверялся. Теперь сначала строится текст,
    затем планка подгоняется под его bounding box с полями 9 и 4.5 мм
    (итог 138x17x3), и в скрипте проверяется вхождение букв в габарит.
    [bin.f3d, binstack-print-assembly.f3d, binstack-print-assembly.step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]
2026-08-18 Тест-кит малых купонов и детент с реальным натягом
    Кит переделан на маленькие купоны (~25 см3 всего): кусок полоза 45 мм,
    слайдер с фланцем, кусок стенки с пазом, огрызок перегородки 20 мм,
    башмак-подставка. Проверка выявила, что детент 0.7 при люфте паза 0.8
    давал натяг -0.1 (щелчка не было) — поднят до 1.0 в ките и в сборке.
    Оба документа Fusion сохранены: BINSTACK P Assembly и BINSTACK P Test Kit.
    [bin.f3d, binstack-print-assembly.f3z.f3d, binstack-print-assembly.step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]
2026-08-18 Тест-кит в печатной ориентации: 33 минуты вместо двух часов
    Купоны переставлены плашмя (высота набора 12 мм вместо 26), урезаны до
    минимума, башмак убран, слой 0.25. Было 1ч49м и 22.7 г, стало 33 мин и
    7.5 г. G-code нарезан под PETG и загружен на принтер.
    [bin.f3d, binstack-print-assembly.f3z.f3d, binstack-print-assembly.step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]
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2026-08-18 Боковины облегчены фермой: минус 52 процента пластика
    Расчёт нагрузок показал запас по прочности ~2700 крат при 4.5 кг груза,
    поэтому материал убран из всех неработающих зон: стенка 8 -> 5 мм (сдвинута
    к полозьям, посадки лотков не изменились) плюс треугольная ферма Warren с
    раскосами 4 мм, наклонённая вдоль полозьев. Силовой контур 7 мм по периметру,
    полосы вдоль полозьев и узлы шипов сохране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
    [bin.f3d, binstack-print-assembly.f3d, binstack-print-assembly.f3z.f3d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]
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
